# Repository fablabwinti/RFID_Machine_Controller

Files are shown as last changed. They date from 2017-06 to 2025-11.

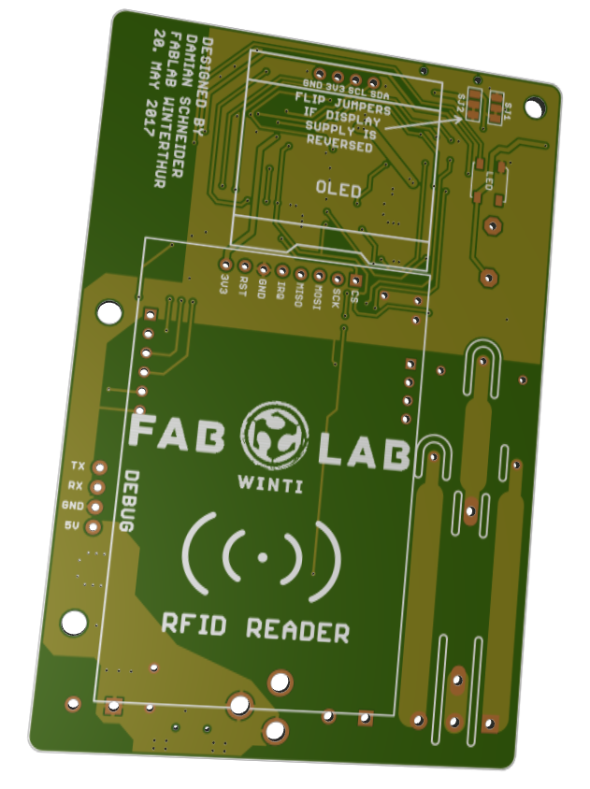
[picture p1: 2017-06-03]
Hardware/PCB_BottomView.PNG

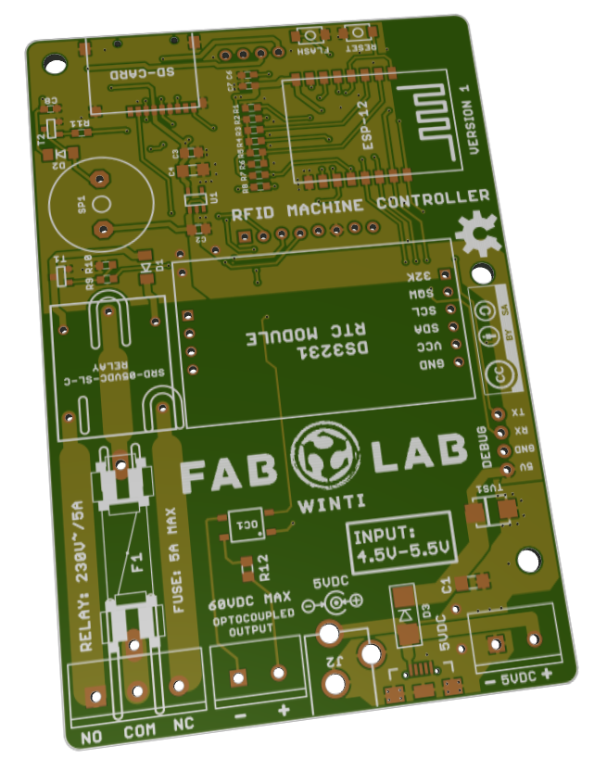
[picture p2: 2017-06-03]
Hardware/PCB_TopView.PNG

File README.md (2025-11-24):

# RFID_Machine_Controller
This repository contains the hardware design files (eagle) and the firmware (Arduino) for the Fablab Winti RFID machine access controller. 
## Hardware features
- Based on ESP8266 so it has direct access to WiFi
- RFID reader 
- OLED display
- Piezo buzzer
- Multi-color LED
- SD card for event logging
- RTC for accurate time keeping without network access
- Isolated output with screw terminal
  - Option 1: Relay output: 250V, 5A, NC or NO with a 5x20mm fuse
  - Option 2: Opto-coupled output (50V, 40mA)
- Input voltage: 5V ±0.5V with input protection (reverse voltage protection, overvoltage protection)
- Three input connecters: 5.5x2.1mm DC jack, Micro USB jack, screw termianl

## Firmware features
- Easy web based configuration
- Time sync through NTP
- Automatic synchronization of local RTC 
- Automatic update of user database from server
- Local storage of access rights: works during network failures
- Local data logging to SD-Card or Flash (TBD)
- Transmit log data to server as soon as it is available

## Arduino IDE
### Add Board to IDE
File -> Preferences -> Settings -> Additional boards manager URLs: http://arduino.esp8266.com/stable/package_esp8266com_index.json  
### Install Board
Tools -> Boards -> Boards Manager
Search for "esp8266" and install it
### Select Board
Tools -> Boards -> esp8622 -> "Generic ESP8622 Module"
### Board Configurations
Select the following settings under "Tools"



### Install Libraries
Unzip "FabLabRFID_Library.zip" in the arduino library folder:

- Windows: `C:\Users\{username}\Documents\Arduino`
- macOS: `/Users/{username}/Documents/Arduino`
- Linux: `/home/{username}/Arduino`

#### Manually

Tools -> Manage Libraries

Install all libraries as described in Fablab_RFID_control.ino, line 52 to 70 (?)

MRFC522: Download from git (https://github.com/miguelbalboa/rfid) and add it to the library (.../Documents/Arduino/Libraries/...)

## Upload Flash Content

The `spiffs_flash.py` script automatically builds the SPIFFS filesystem image from the `data` directory and uploads it to the ESP8266.

### Prerequisites
- Python 3.x installed
- ESP8266 connected via USB
- Arduino15 directory present (auto-detected or manually specified)

### Usage

Basic upload (auto-detects Arduino15 directory):
```bash
python spiffs_flash.py --port COM8
```

With custom options:
```bash
# Specify Arduino15 directory manually
python spiffs_flash.py --port COM8 --arduino-root "C:\Users\YourName\AppData\Local\Arduino15"

# Erase SPIFFS region before writing (if write fails)
python spiffs_flash.py --port COM8 --erase-region

# Keep temporary build files for inspection
python spiffs_flash.py --port COM8 --keep-temp

# Use existing .bin file (skip build)
python spiffs_flash.py --port COM8 --bin path\to\existing.spiffs.bin
```

### Troubleshooting
- If Arduino15 not found, the script will prompt for the path
- Use `--erase-region` if you encounter write errors (preserves main firmware)
- Change COM port number to match your device (check Device Manager on Windows)

# License
-Firmware under GNU LGPL Version 3
-Hardware under Creative Commons 4.0 license: CC-BY-SA

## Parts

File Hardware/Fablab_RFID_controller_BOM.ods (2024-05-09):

Bill of materials for the Fablab RFID machine access conroller / logger
Part | Description | Quantity | Price per piece | Ordering information | Order Quantitiy | Ordering Price
PCB |  | 1 | 2.85 | Seeedstudio, DHL shipping (https://www.seeedstudio.com/fusion_pcb.html) | 10 | 28.5
SUP | 5V 2A Power supply | 1 | 2.84 | Aliexpress (https://www.aliexpress.com/item/1PCS-5V2A-New-AC-100V-240V-Converter-Adapter-DC-5V-2A-2000mA-Power-Supply-EU-Plug/32277477479.html) | 10 | 28.37
TF Card | micro SD card, 2GB | 1 | 2.8 | Aliexpress (https://www.aliexpress.com/item/10pcs-lot-microsd-tf-card-2gb-2gb-micro-tf-card-transflash-2gb-with-free-memory-card/496106309.html) | 10 | 28
C1 | 100uF, 1206, X7R, 16V | 1 | 0.18 | Aliexpress (https://www.aliexpress.com/item/Free-Shipping-50PCS-1206-107M-100UF-20-X7R-16V-chip-SMD-Ceramic-capacitor-3216-1206-SMD/32639706932.html) | 50 | 8.8
C2, C3 | 10uF, 0805, X7R, 25V | 2 | 0.08 | Aliexpress (https://www.aliexpress.com/item/100pcs-lot-10uF-X7R-Error-10-25V-0805-smd-capacitor/32319279591.html) | 100 | 4
C6, C7, C8 | 100nF, 0603, X7R, 50V | 3 | 0.02 | Aliexpress (https://www.aliexpress.com/item/100pcs-lot-100nF-X7R-Error-10-50V-0805-smd-capacitor/32318938808.html) | 500 | 2.7
D1 | 1N4148, Minimelf | 1 | 0 | Aliexpress (https://www.aliexpress.com/item/Free-shipping-100PCS-LL4148-LL-34-1N4148-IN4148-smd-High-speed-switching-diodes/32334460408.html) | 500 | 1.8
D3 | 1A, Schottky, SMA | 1 | 0.01 | Aliexpress (https://www.aliexpress.com/item/Free-shipping-100pcs-sma-1n5819-smd-1A-40V-do-214ac-Schottky-diode-SOt-23-diode-ss14/32337470783.html) | 100 | 1
F1 | Fuse holder | 1 | 0.14 | Aliexpress (https://www.aliexpress.com/item/10PCS-Panel-Mount-PCB-Fuse-Holder-Case-w-Cover-5x20mm-With-Transparent-Cover-5-20-High/32761598754.html) | 10 | 1.4
F1-2 | 5A Fuse, 5x20mm | 1 | 0.15 | Aliexpress (https://www.aliexpress.com/item/50pcs-Ceramic-tube-6-30mm-20A-250V-6X30-Quick-break-F20A/32523716039.html) | 30 | 4.5
B1, B2 | Tactaile button | 2 | 0.15 | Aliexpress (https://www.aliexpress.com/item/20pcs-smd-3-4-2MM-Micro-button-3X4X2-tact-switch-2-pin-little-turtle-single-shrapnel/32530022647.html) | 20 | 1.45
SD | SD-Card Slot | 1 | 0.27 | Aliexpress (https://www.aliexpress.com/item/10pcs-lot-Trans-Flash-TF-Micro-SD-Card-Socket-Adapter-pop-up-micro-TF-memory-card/32297753919.html) | 10 | 2.7
J1 | 5.5x2.1 DC Jack | 1 | 0.06 | Aliexpress (https://www.aliexpress.com/item/20PCS-LOT-DC-005-Black-and-White-DC-Power-Jack-Socket-Connector-DC005-5-5-2/32730260523.html) | 20 | 1.15
JP6 | Screw Terminal 3P | 1 | 0.15 | Aliexpress (https://www.aliexpress.com/item/10Pcs-Lot-KF301-3P-KF301-5-0MM-3P-Blue-KF301-Screw-3Pin-5-0mm-Straight/32732383478.html) | 20 | 3
JP8, JP9 | Screw Terminal 2P | 2 | 0.3 | Aliexpress (https://www.aliexpress.com/item/10Pcs-5mm-5-08mm-2Pins-2P-2-PINS-PCB-Screw-Terminal-Block-Connectors-300V-10A-DG128/32691479684.html) | 10 | 1.5
LED | WS2812B | 1 | 0.25 | Aliexpress (https://www.aliexpress.com/item/10-1000pcs-WS2812B-4pins-5050-SMD-Black-White-version-WS2812-Individually-Addressable-Digital-RGB-LED-Chip/32453497583.html) | 10 | 2.5
OC1 | EL357 optocoupler | 1 | 0.07 | Aliexpress (https://www.aliexpress.com/item/Free-shipping-20pcs-EL357NC-SMD-Optocoupler-EL357-EL357N/32341947060.html) | 20 | 1.3
R1, R2, R3, T4, R5, R7, R10, R13 | 10k, 0603 | 8 | 0.08 | Aliexpress 0603 Resistor Kit (https://www.aliexpress.com/item/Free-shipping-Hot-sale-0603-SMD-Resistor-Kit-Assorted-Kit-1ohm-10M-ohm-1-36valuesX20pcs-720pcs/32359683117.html) | 20 | 1.85
R6, R9, R11, R12 | 1k, 0603 | 4 | 0.04
R8 | 510R, 0603 | 1 | 0.01
SP1 | Piezo Speaker | 1 | 0.29 | Aliexpress (https://www.aliexpress.com/item/10pcs-Piezoelectric-Piezo-Passive-Electronic-Buzzer-Speaker-14-7-Loudspeaker-1407-5V-14x7mm-4KHz-2mA-Black/32802296078.html) | 10 | 2.85
T1, T2 | NPN 40V, 0.6A SOT23 | 2 | 0.03 | Aliexpress (https://www.aliexpress.com/item/MMBT2222A-SOT-23-500pcs-lot-Triode-Transistor/32311239794.html) | 100 | 1.4
TVS1 | SMBJ5.0CA | 1 | 0.06 | Aliexpress (https://www.aliexpress.com/item/Free-shipping-20pcs-600W-SMB-DO-214AA-smd-tvs-diode-SMBJ5-0CA/32338238265.html) | 20 | 1.2
OLED | 0.96" OLED Display | 1 | 2.56 | Aliexpress (https://www.aliexpress.com/item/10pcs-0-96-white-0-96-inch-OLED-module-New-128X64-OLED-LCD-LED-Display-Module/32643753358.html) | 10 | 25.6
USB | Micro USB Jack | 1 | 0.03 | Aliexpress (https://www.aliexpress.com/item/10PCS-RT9013-33PB-RT9013-SOT23-5-RT9013-33/32699079131.html) | 100 | 3.3
REL1 | SRD-05VDC-SL-C Relay | 1 | 0.56 | Aliexpress (https://www.aliexpress.com/item/T73-5VDC-SONGLE-Power-Relay-SRD-05VDC-SL-C-PCB-Type-20pcs-Free-Shipping/32520810798.html) | 20 | 11.2
ESP | ESP-12F Module | 1 | 2.13 | Aliexpress (https://www.aliexpress.com/item/10pcs-2015-New-version-1PCS-ESP-12F-ESP-12E-upgrade-ESP8266-remote-serial-Port-WIFI-wireless/32589865366.html) | 10 | 21.3
RFID | MFRC-522 Module | 1 | 1.69 | Aliexpress (https://www.aliexpress.com/item/MFRC-522-RC522-RFID-RF-IC-card-sensor-module-to-send-S50-Fudan-card-keychain-for/1654370096.html) | 10 | 16.9
RTC | DS3231 RTC Module | 1 | 1.36 | Aliexpress (https://www.aliexpress.com/item/MFRC-522-RC522-RFID-RF-IC-card-sensor-module-to-send-S50-Fudan-card-keychain-for/1654370096.html) | 10 | 13.6
IC1 | RT9013-33PB SOT23-5 | 1 | 0.2 | Aliexpress (https://www.aliexpress.com/item/10PCS-RT9013-33PB-RT9013-SOT23-5-RT9013-33/32699079131.html) | 20 | 3.98
 | Price per Unit* |  | 19.34 |  | Total Order Price | 225.85
*if ordering of exactly 10 parts

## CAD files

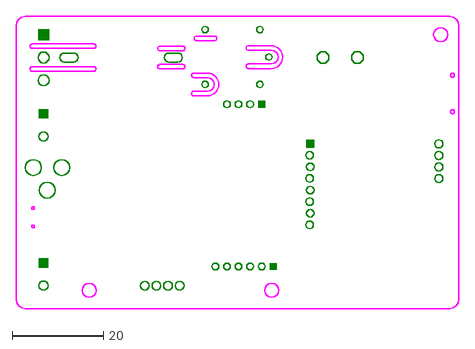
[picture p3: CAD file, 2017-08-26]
Hardware/Fablab_RFID_conroller_V1.dxf
97.0 x 64.0

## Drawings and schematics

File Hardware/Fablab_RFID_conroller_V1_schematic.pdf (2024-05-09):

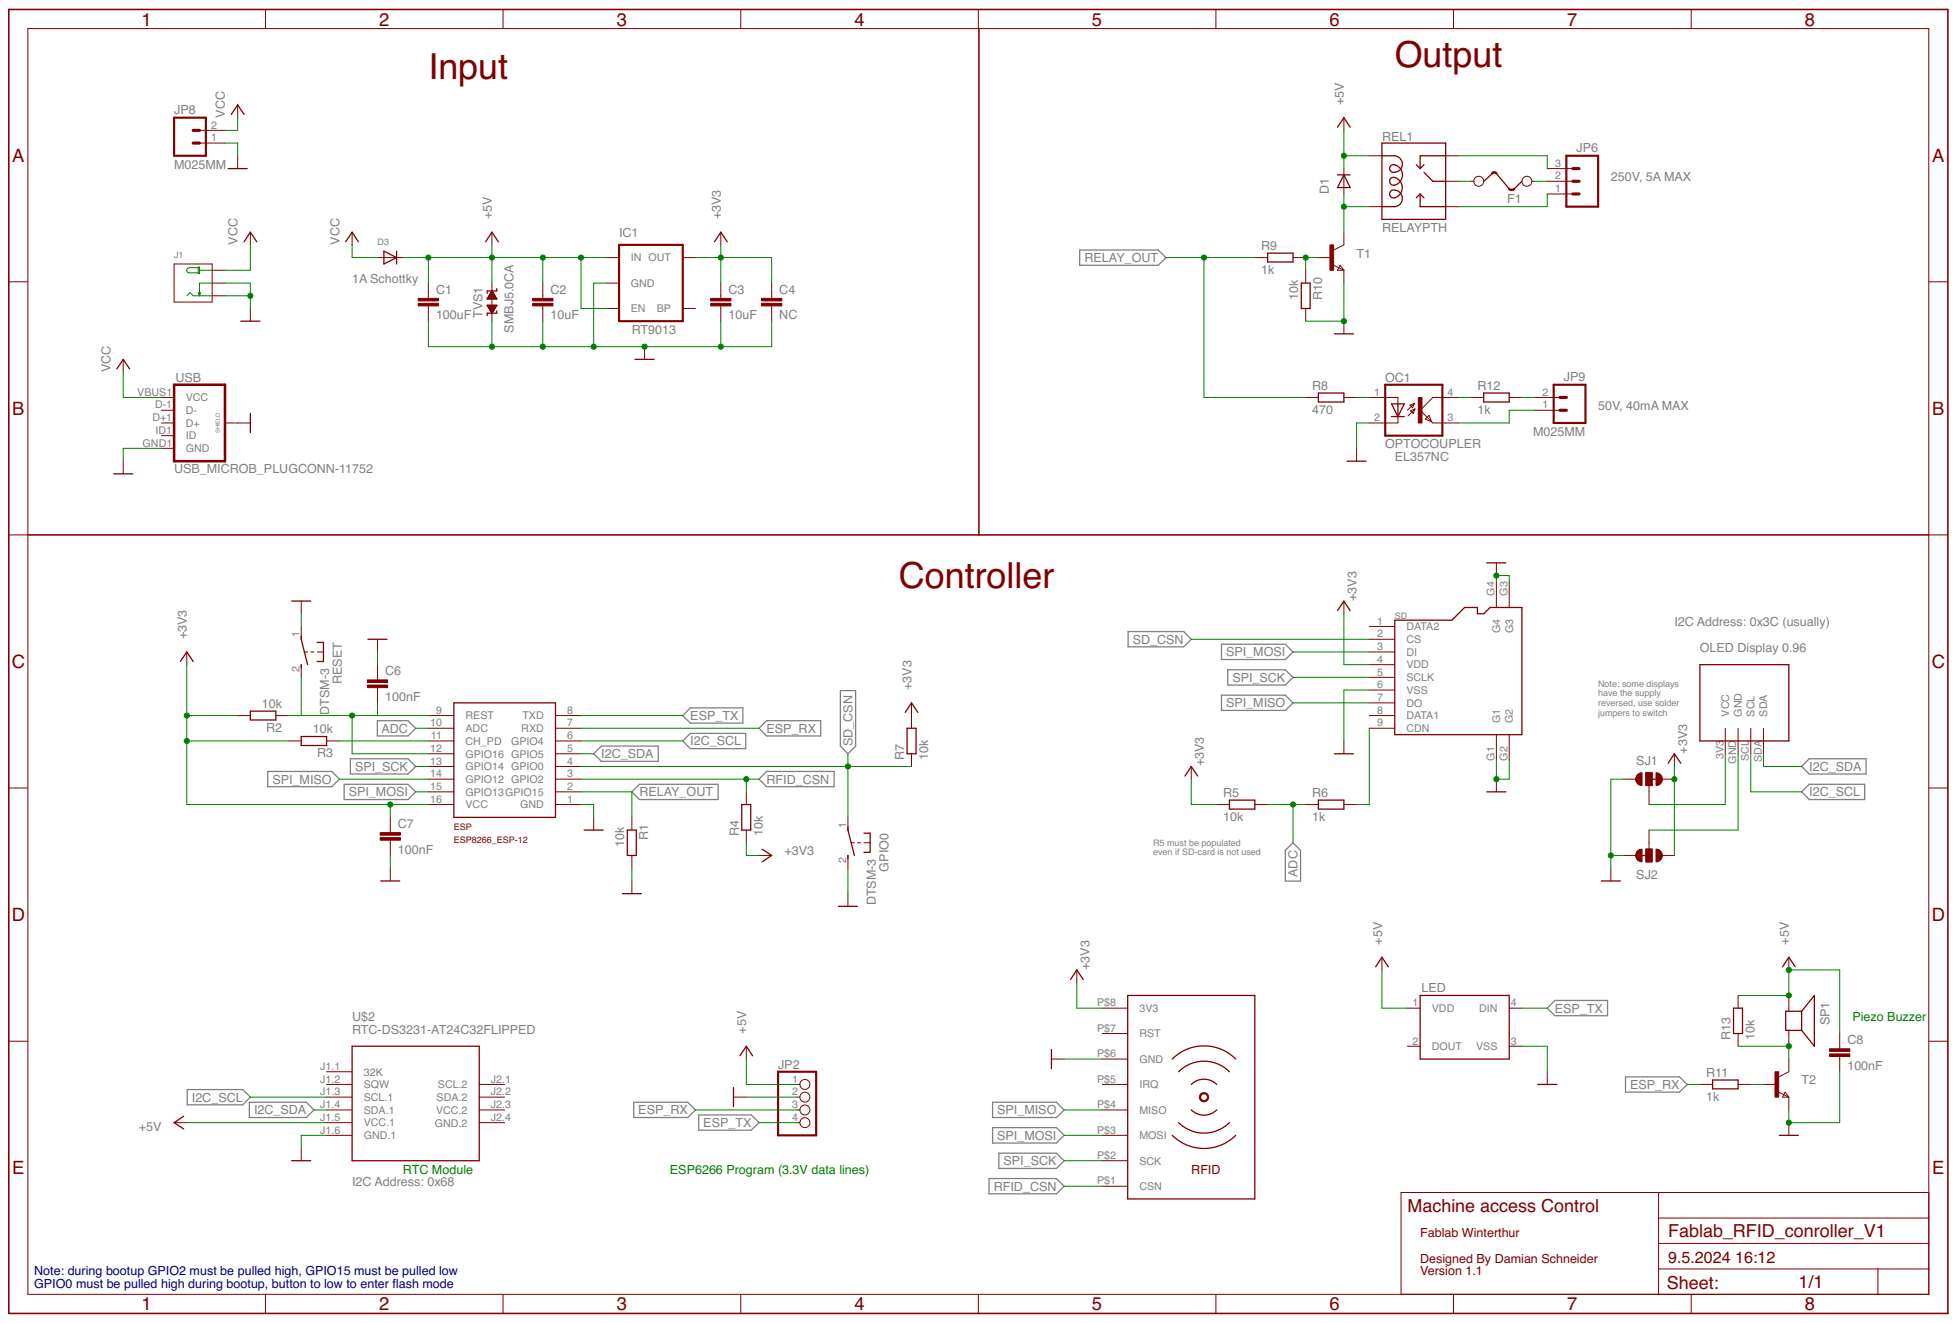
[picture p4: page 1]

Input | Output

Note: some displays have the supply

3 GPIO0 2 GPIO2

R5 must be populated
even if SD-card is not used

Machine access Control Fablab Winterthur Designed By Damian Schneider Version 1.1

Note: during bootup GPIO2 must be pulled high, GPIO15 must be pulled low GPIO0 must be pulled high during bootup, button to low to enter flash mode

Sheet: 1/1

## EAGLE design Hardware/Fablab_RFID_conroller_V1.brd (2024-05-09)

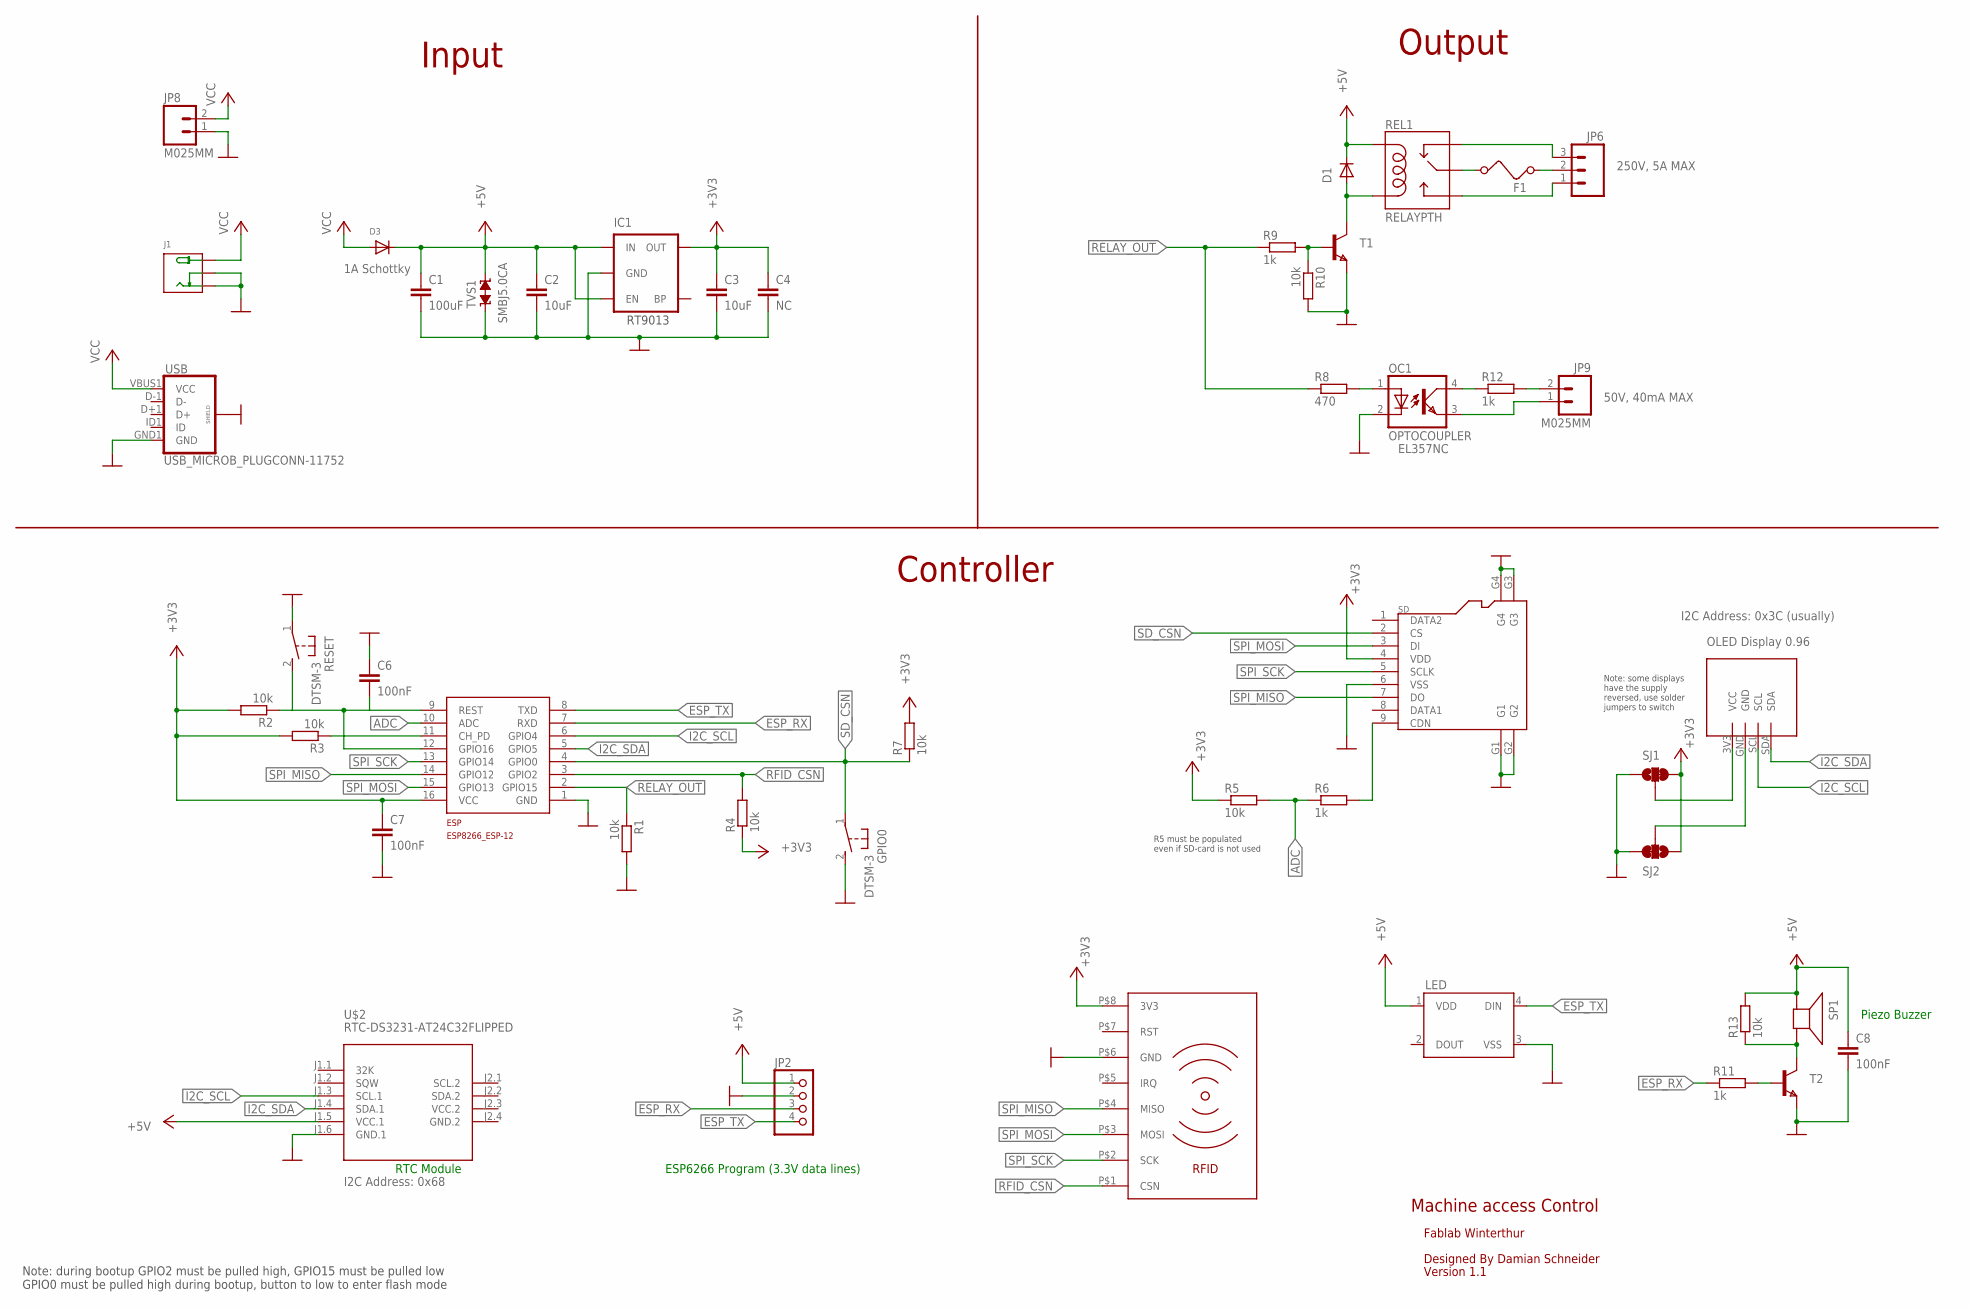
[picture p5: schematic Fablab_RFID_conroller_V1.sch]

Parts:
C1: 100uF; C1206
C2, C3: 10uF; C0805
C4: NC; C1206
C6, C7, C8: 100nF; C0603
D1: DIODE-MINIMELF; MINIMELF
D3: DIODESMA; SMADIODE
ESP: ESP8266_ESP-12; ESP8266-ESP12
F1: FUSE
GPIO0: DTSM-3
IC1: V_REG_LDOSMD; SOT23-5
J1: JACK-DC-3P-3410020P1; PW-3P-2.1
JP2: HEADER-1X476MIL; 1X04_ROUND_76
JP6: M03-SCREW-5MM; SCREWTERMINAL-5MM-3
JP8, JP9: M025MM; SCREWTERMINAL-5MM-2
LED: WS2812B
OC1: OPTOCOUPLER; SOP04
OLED: OLED_0.96_I2CNOHOLES; OLED_0.96_I2C_NOHOLES
R1, R2, R3, R4, R5, R7, R10, R13: 10k; R0603
R6, R9, R11: 1k; R0603
R8: 470; R0603
R12: 1k; R0805
REL1: RELAYPTH; SRD-05VDC-SL-C
RESET: DTSM-3
RFID: RFID_MODULE_RC522; RFID-RC522-MODULE
SD: MICRO-SDCARD-CONNECTOR-3300060P1; 9P-SMD-W-RING
SJ1, SJ2: JUMPER-PAD-3-2OF3_NC_BY_TRACE_LARGE; PAD-JUMPER-3-2OF3_NC_BY_TRACE_YES_SILK_LARGE
SP1: SPEAKER/AL60P; AL60P
T1, T2: NPNSOT23; SOT-23
TVS1: TVS-SMBJ; SMBJ
U$2: RTC-DS3231-AT24C32FLIPPED; RTC-DS3231_FLIPPED
USB: USB_MICROB_PLUGCONN-11752; USB-B-MICRO-SMD_V03

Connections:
!SDCARD_DETECT: R6.2, SD.9 (CDN)
+3V3: C3.1, C4.1, C7.1, ESP.16 (VCC), IC1.5 (OUT), R2.2, R3.2, R4.1, R5.1, R7.2, RFID.P$8 (3V3), SD.4 (VDD), SJ1.3, SJ2.1
+5V: C1.1, C2.1, C8.1, D1.C, D3.C, IC1.1 (IN), IC1.3 (EN), JP2.1, LED.1 (VDD), R13.2, REL1.COIL1, SP1.1 (+), TVS1.C (2), U$2.J1.5 (VCC.1)
ADC: ESP.10 (ADC), R5.2, R6.1
CHPD: ESP.11 (CH_PD), R3.1
ESP_RX: ESP.7 (RXD), JP2.3, R11.1
ESP_TX: ESP.8 (TXD), JP2.4, LED.4 (DIN)
GND: C1.2, C2.2, C3.2, C4.2, C6.1, C7.2, C8.2, ESP.1 (GND), GPIO0.2, IC1.2 (GND), J1.-1 (-), J1.-2 (CDN), JP2.2, JP8.1, LED.3 (VSS), OC1.2 (C), R1.2, R10.2, RESET.1, RFID.P$6 (GND), SD.6 (VSS), SD.G1, SD.G2, SD.G3, SD.G4, SJ1.1, SJ2.3, T1.2 (E), T2.2 (E), TVS1.A (1), U$2.J1.6 (GND.1), USB.GND1 (GND), USB.SHIELD1 (SHIELD), USB.SHIELD2 (SHIELD), USB.SHIELD3 (SHIELD)
GND.2: U$2.J2.4 (GND.2)
I2C_SCL: ESP.6 (GPIO4), OLED.SCL, U$2.J1.3 (SCL.1)
I2C_SDA: ESP.5 (GPIO5), OLED.SDA, U$2.J1.4 (SDA.1)
unnamed: JP9.2, R12.2
unnamed: OLED.3V3 (VCC), SJ1.2
unnamed: OLED.GND, SJ2.2
unnamed: R9.2, R10.1, T1.3 (B)
unnamed: D1.A, REL1.COIL0, T1.1 (C)
unnamed: R13.1, SP1.2 (-), T2.1 (C)
unnamed: R11.2, T2.3 (B)
unnamed: F1.1, JP6.2
unnamed: JP6.1, REL1.SW_NO (SWOPEN)
unnamed: F1.2, REL1.SWCOMMON
unnamed: JP6.3, REL1.SW_NC (SWCLOSE)
unnamed: OC1.1 (A), R8.2
unnamed: OC1.4 (COL), R12.1
unnamed: JP9.1, OC1.3 (EMIT)
RELAY_OUT: ESP.2 (GPIO15), R1.1, R8.1, R9.1
RESET: C6.2, ESP.9 (REST), ESP.12 (GPIO16), R2.1, RESET.2
RFID_CSN: ESP.3 (GPIO2), R4.2, RFID.P$1 (CSN)
SD_CSN: ESP.4 (GPIO0), GPIO0.1, R7.1, SD.2 (CS)
SPI_MISO: ESP.14 (GPIO12), RFID.P$4 (MISO), SD.7 (DO)
SPI_MOSI: ESP.15 (GPIO13), RFID.P$3 (MOSI), SD.3 (DI)
SPI_SCK: ESP.13 (GPIO14), RFID.P$2 (SCK), SD.5 (SCLK)
VCC: D3.A, J1.+, JP8.2, USB.VBUS1 (VCC)
VCC.2: U$2.J2.3 (VCC.2)

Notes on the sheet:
ESP6266 Program (3.3V data lines)
Note: during bootup GPIO2 must be pulled high, GPIO15 must be pulled low GPIO0 must be pulled high during bootup, button to low to enter flash mode
Piezo Buzzer
OLED Display 0.96
R5 must be populated even if SD-card is not used
RTC Module
RT9013
Machine access Control
Fablab Winterthur
Designed By Damian Schneider
EL357NC
50V, 40mA MAX
250V, 5A MAX
I2C Address: 0x68
I2C Address: 0x3C (usually)
1A Schottky
SMBJ5.0CA
Input
Output
Controller
Note: some displays have the supply reversed, use solder jumpers to switch
Version 1.1

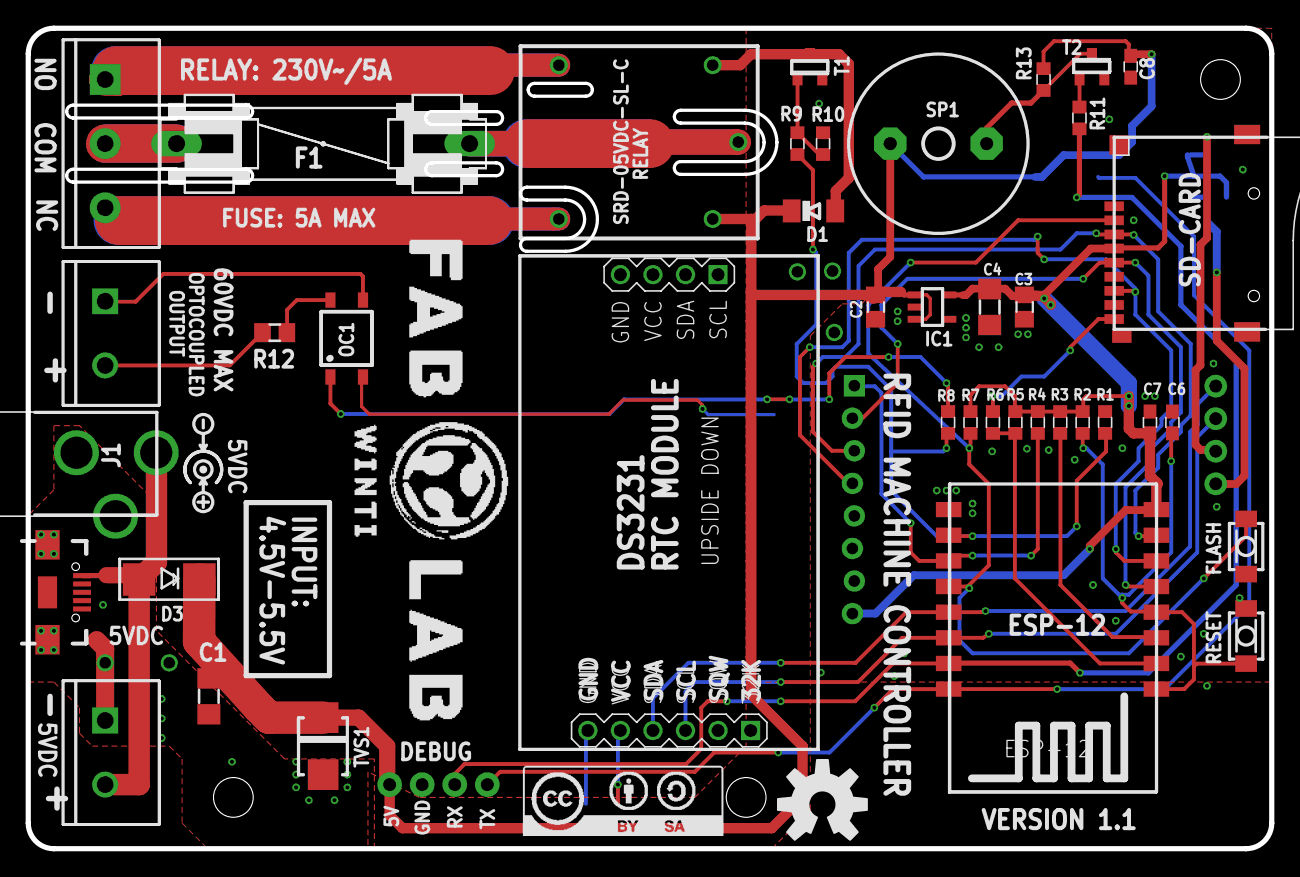
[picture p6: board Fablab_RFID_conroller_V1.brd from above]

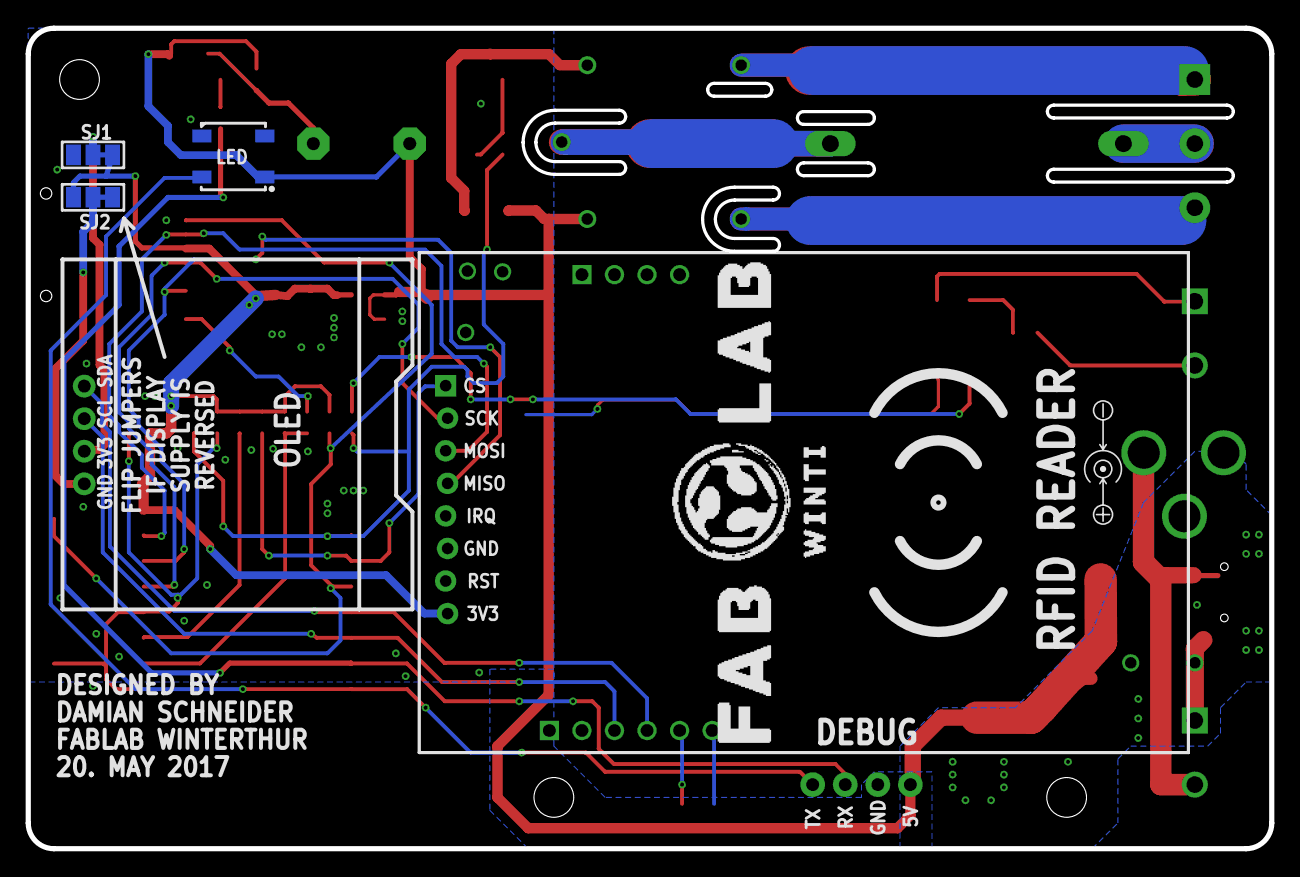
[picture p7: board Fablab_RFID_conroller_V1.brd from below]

Board: 2 copper layers, 97.0 x 64.0 mm, 47 parts (5 on the bottom side), 32 nets.

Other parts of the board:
U$6: OSHW-LOGO-L

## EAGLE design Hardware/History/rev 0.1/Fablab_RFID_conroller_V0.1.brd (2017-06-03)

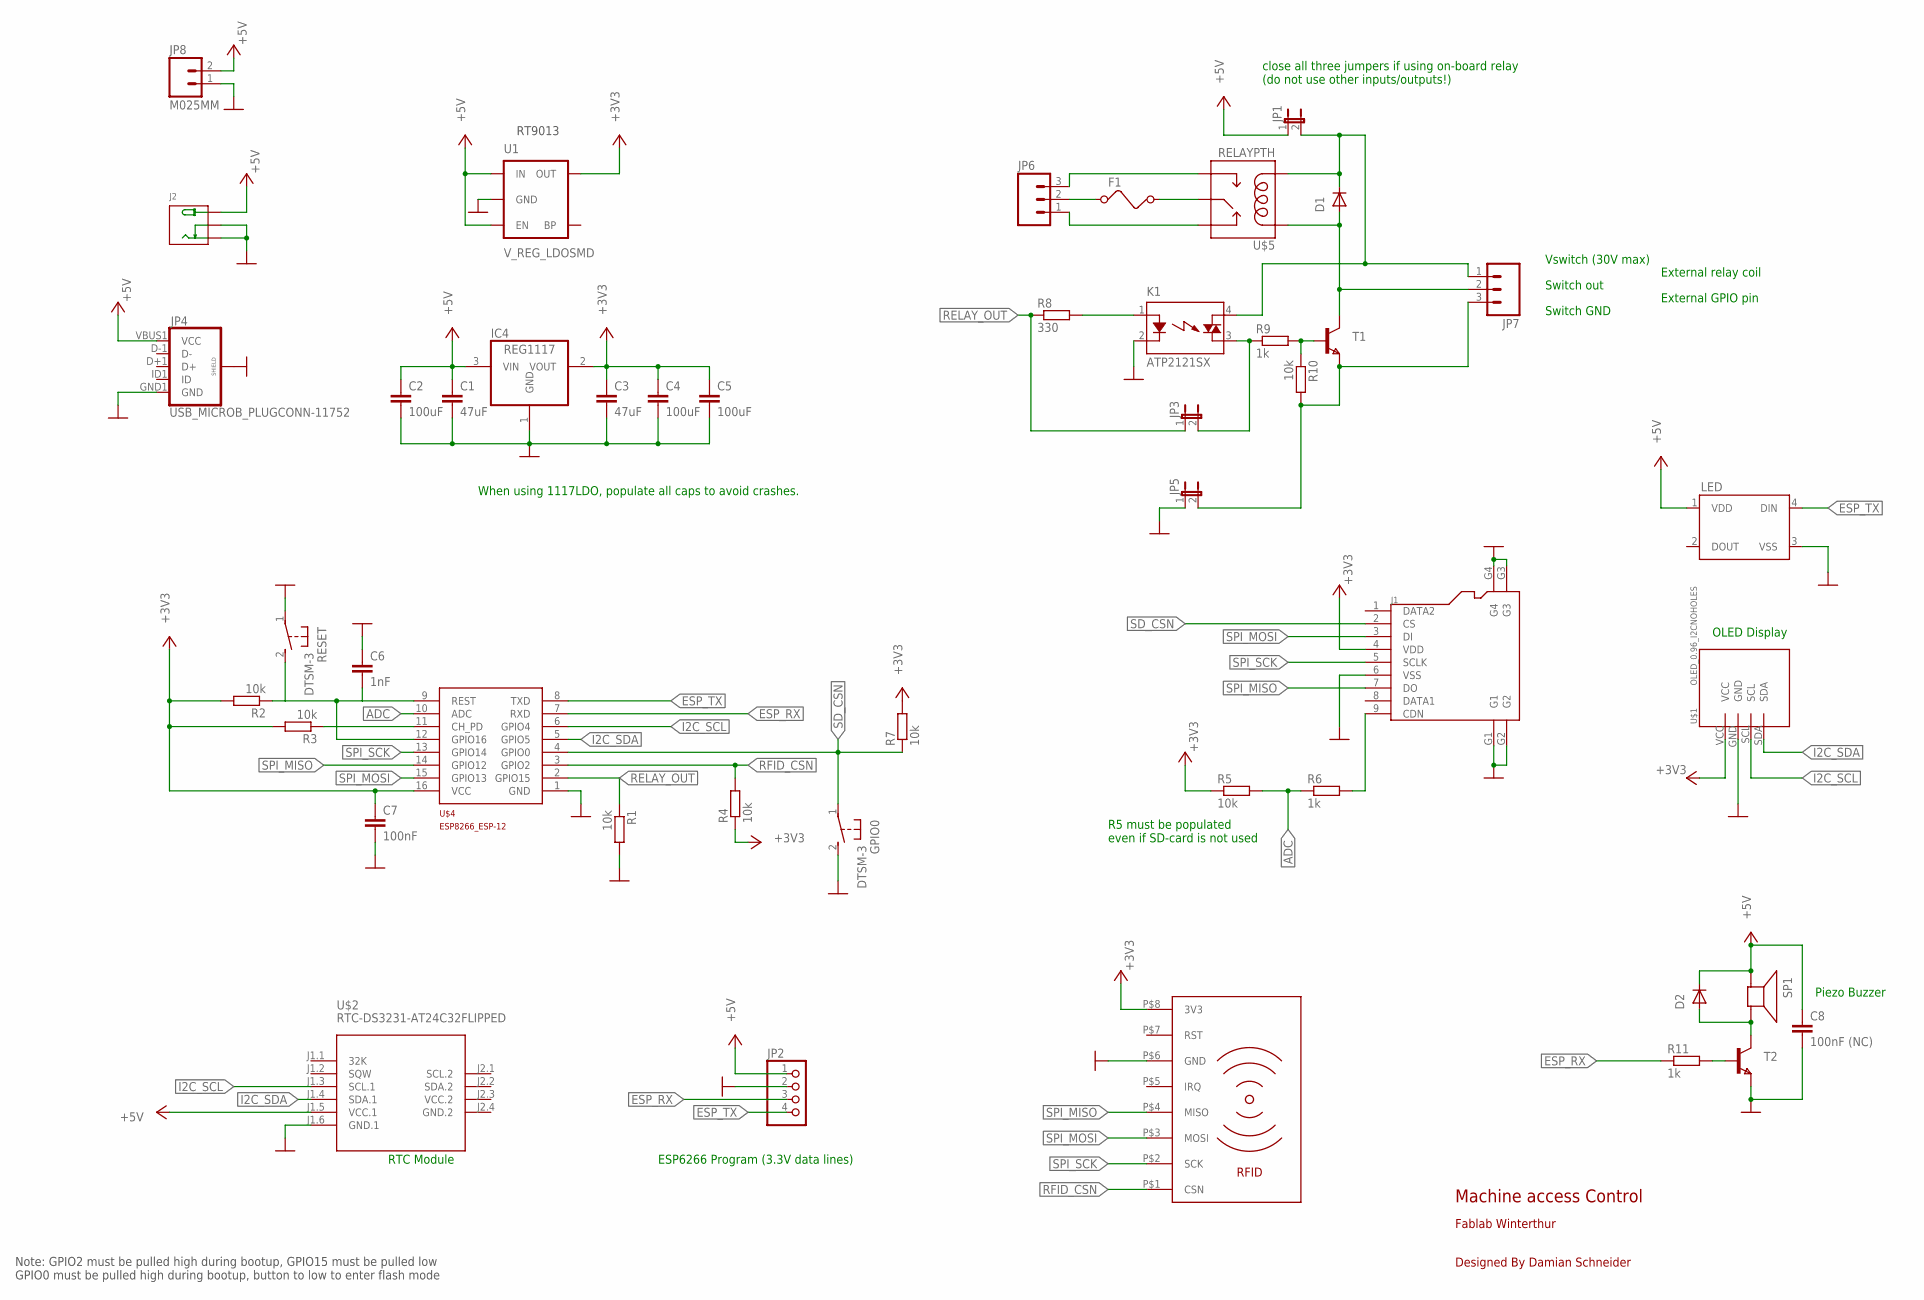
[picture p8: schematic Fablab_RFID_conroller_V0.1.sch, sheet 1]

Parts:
C1, C3: 47uF; C0805
C2, C4, C5: 100uF; C1206
C6: 1nF; C0603
C7: 100nF; C0603
C8: 100nF (NC); C0603
D1, D2: DIODE-MINIMELF; MINIMELF
F1: FUSE
GPIO0: DTSM-3
IC4: REG1117; SOT223
J1: MICRO-SDCARD-CONNECTOR-3300060P1; 9P-SMD-W-RING
J2: JACK-DC-3P-3410020P1; PW-3P-2.1
JP1, JP3, JP5: JP1E; JP1
JP2: HEADER-1X476MIL; 1X04_ROUND_76
JP4: USB_MICROB_PLUGCONN-11752; USB-B-MICRO-SMD_V03
JP6, JP7: M03-SCREW-5MM; SCREWTERMINAL-5MM-3
JP8: M025MM; SCREWTERMINAL-5MM-2
K1: ATP2121SX; SOP04
LED: WS2812B
R1, R2, R3, R4, R5, R7, R10: 10k; R0603
R6, R9, R11: 1k; R0603
R8: 330; R0603
RESET: DTSM-3
SP1: SPEAKER/AL60P; AL60P
T1, T2: NPNSOT23; SOT-23
U1: V_REG_LDOSMD; SOT23-5
U$1: OLED_0.96_I2CNOHOLES; OLED_0.96_I2C_NOHOLES
U$2: RTC-DS3231-AT24C32FLIPPED; RTC-DS3231_FLIPPED
U$3: RFID_MODULE_RC522; RFID-RC522-MODULE
U$4: ESP8266_ESP-12; ESP8266-ESP12
U$5: RELAYPTH; SRD-05VDC-SL-C

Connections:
!SDCARD_DETECT: J1.9 (CDN), R6.2
+3V3: C3.1, C4.1, C5.1, C7.1, IC4.2 (VOUT), J1.4 (VDD), R2.2, R3.2, R4.1, R5.1, R7.2, U1.5 (OUT), U$1.VCC, U$3.P$8 (3V3), U$4.16 (VCC)
+5V: C1.1, C2.1, C8.1, D2.C, IC4.3 (VIN), J2.+, JP1.1, JP2.1, JP4.VBUS1 (VCC), JP8.2, LED.1 (VDD), SP1.1 (+), U1.1 (IN), U1.3 (EN), U$2.J1.5 (VCC.1)
ADC: R5.2, R6.1, U$4.10 (ADC)
CHPD: R3.1, U$4.11 (CH_PD)
ESP_RX: JP2.3, R11.1, U$4.7 (RXD)
ESP_TX: JP2.4, LED.4 (DIN), U$4.8 (TXD)
GND: C1.2, C2.2, C3.2, C4.2, C5.2, C6.1, C7.2, C8.2, GPIO0.2, IC4.1 (GND), J1.6 (VSS), J1.G1, J1.G2, J1.G3, J1.G4, J2.-1 (-), J2.-2 (CDN), JP2.2, JP4.GND1 (GND), JP4.SHIELD1 (SHIELD), JP4.SHIELD2 (SHIELD), JP4.SHIELD3 (SHIELD), JP5.1, JP8.1, LED.3 (VSS), R1.2, RESET.1, T2.2 (E), U1.2 (GND), U$1.GND, U$2.J1.6 (GND.1), U$3.P$6 (GND), U$4.1 (GND)
GND.2: U$2.J2.4 (GND.2)
I2C_SCL: U$1.SCL, U$2.J1.3 (SCL.1), U$4.6 (GPIO4)
I2C_SDA: U$1.SDA, U$2.J1.4 (SDA.1), U$4.5 (GPIO5)
unnamed: K1.1 (A), R8.2
unnamed: JP3.2, K1.3 (DS2), R9.1
unnamed: R9.2, R10.1, T1.3 (B)
unnamed: D1.A, JP7.2, T1.1 (C), U$5.COIL1
unnamed: JP5.2, JP7.3, R10.2, T1.2 (E)
unnamed: D2.A, SP1.2 (-), T2.1 (C)
unnamed: JP1.2, JP7.1, K1.4 (DS1)
unnamed: D1.C, U$5.COIL0
unnamed: R11.2, T2.3 (B)
unnamed: F1.1, JP6.2
unnamed: JP6.3, U$5.SW_NO (SWOPEN)
unnamed: F1.2, U$5.SWCOMMON
unnamed: JP6.1, U$5.SW_NC (SWCLOSE)
RELAY_OUT: JP3.1, R1.1, R8.1, U$4.2 (GPIO15)
RESET: C6.2, R2.1, RESET.2, U$4.9 (REST), U$4.12 (GPIO16)
RFID_CSN: R4.2, U$3.P$1 (CSN), U$4.3 (GPIO2)
SD_CSN: GPIO0.1, J1.2 (CS), R7.1, U$4.4 (GPIO0)
SPI_MISO: J1.7 (DO), U$3.P$4 (MISO), U$4.14 (GPIO12)
SPI_MOSI: J1.3 (DI), U$3.P$3 (MOSI), U$4.15 (GPIO13)
SPI_SCK: J1.5 (SCLK), U$3.P$2 (SCK), U$4.13 (GPIO14)
VCC.2: U$2.J2.3 (VCC.2)

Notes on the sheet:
ESP6266 Program (3.3V data lines)
Note: GPIO2 must be pulled high during bootup, GPIO15 must be pulled low GPIO0 must be pulled high during bootup, button to low to enter flash mode
Piezo Buzzer
OLED Display
R5 must be populated even if SD-card is not used
RTC Module
Vswitch (30V max)
Switch GND
Switch out
External relay coil
External GPIO pin
close all three jumpers if using on-board relay (do not use other inputs/outputs!)
RT9013
When using 1117LDO, populate all caps to avoid crashes.
Machine access Control
Fablab Winterthur
Designed By Damian Schneider

Board: 2 copper layers, 46 parts (3 on the bottom side), 30 nets, no tracks yet.

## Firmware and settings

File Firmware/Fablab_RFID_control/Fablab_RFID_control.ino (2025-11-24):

/*
  Hardare: Use only ESP8266 with 4M of flash, then select 4M (with 2M SPIFFS) (need extras sketch space to enable update throug webpage and future increases, 2M SPIFFS is plenty)

  TODO: add license here ( GNU LGPL Version 3 ), also add license to GIT repo

  FabLab RFID controller, by Damian Schneider, www.fablabwinti.ch
  GIT: https://github.com/fablabwinti/RFID_Machine_Controller



  Tested on Arduino 1.8.5 using ESP8266 Arduino V2.4.0  (https://github.com/esp8266/Arduino/releases)
  For tested library versions, see next to their includes.



  Note on data structure

  -the configuration of the node resides in "eeprom" (flash actually). this includes:
    -wifi configuration
    -machine ID, machine name, machine pricing
    -admin tags & access codes

  -the SPIFF file system contains
    -the config web page
    -user IDs and access control stuff (in a database file)
  -logging is done on the SD card:
    -system event log files:
      -booting/rebooting/crash
      -server communication log
      -web page access
  -user login/logout is saved to a separate event database, it is either in SPIFFS or on SD
      -uid, username, transferred to server flag

  Other notes:
    -the display must show: current user name, log time, running price
    -when not logging: current time&date, machine name, machine pricing
    -at bootup: show logo or something
    -maximum number of users: 2000 (limited by database size, can probably be increased but is untested)

    -while a user is logged in, any network activity (RTC sync, sendout events, webpage etc.) are disabled to ensure best stability while the machine is running

  Admin interface stuff:
    -administration is done through the web page
    -the webpage can be activeted only by pressing the function button on the hardware (after bootup)
    -

    Tested on Arduino 1.8.9 and 1.8.12
    ESP version 2.5.2 (Not working with 2.6.x !!! something changed in the wifisecure library)

    Libraries used:
  Using library EDB at version 1.0.4   https://github.com/jwhiddon/EDB
  Using library SPI at version 1.0
  Using library MRFC522 at version 1.4.10
  Using library FastLED at version 3.2.1
  Using library Time at version 1.5   https://github.com/PaulStoffregen/Time
  Using library Rtc_by_Makuna at version 2.0.2   https://github.com/Makuna/Rtc
  Using library Adafruit_SSD1306 at version 1.1.2
  Using library Adafruit_GFX at version 1.2.3
  Using library ESP8266WiFi at version 1.0
  Using library ESP8266WebServer at version 1.0
  Using library ESP8266HTTPClient at version 1.2
  Using library ESP8266httpUpdate at version 1.3
  Using library EEPROM at version 1.0
  Using library Wire at version 1.0
  Using library ESP8266SdFat at version 1.0.16
  Using library ESP8266mDNS at version 1.2
  Using library WebSockets at version 2.0.9
  Using library ArduinoJson at version 6.12.0   https://bblanchon.github.io/ArduinoJson/

 * */

//set these compile time parameters to fit your needs
//#define SERIALDEBUG //define this to get serial console output, LED is disabled if serial output is used

#define TIMEZONE 1 //GMT +1  adjust to your timezone if needed, can be negative
#define SERVERMININTERVAL 1000  // minimum interval (in ms) between server sendouts (where a pending event is sent) default: 1000
#define MULTIWIFIS 2 //number of wifi credentials to store for wifi multi (uses lots of ram in the config!) default: 2
#define SAVE_LOG_TO_SD 1 //if defined, strings sent to the server are also written to the SD (if sendout is successful making it a copy of what should be in the server database)
//#define EVENT_DB_TO_SD 1 //if defined, the event database is saved to the SD-card instead of SPIFFS (useful if writing events every few seconds, usage of spiffs is fine when writing like once per minute or less, spiffs will last 100 million entries or more)

//extern "C" {
//#include "user_interface.h" //for light sleep stuff
//}
#define FS_NO_GLOBALS //allow spiffs to coexist with SD card
#define FASTLED_ESP8266_RAW_PIN_ORDER

#include <FS.h> //spiff file system
#include <EDB.h>
#include <SPI.h>
#include <MFRC522.h> //RFID library
#include <FastLED.h> // (need to comment line 15 in led_sysdefs_esp8266.h on lates esp version, boolean error)
#include <TimeLib.h>  //Time library
#include "RtcDS3231.h" //RTC library by makuna
#include <Adafruit_SSD1306.h> //oled display library
#include <Adafruit_GFX.h>
#include <ESP8266WiFi.h>
#include <ESP8266WiFiMulti.h>
//#include <WiFiClient.h>
#include <WiFiClientSecure.h>
#include <ESP8266WebServer.h>
#include <ESP8266HTTPClient.h>
#include <ESP8266httpUpdate.h>
#include <EEPROM.h>
#include <WiFiUdp.h>
#include <IPAddress.h>
#include <Wire.h>
//#include <SD.h> //SD library has bugs, can often lead to crashes (not even the readwrite example works....)
#include "SdFat.h" //
using namespace sdfat;
#include <ESP8266mDNS.h>  //works on mac out of the box, need to install apple's 'Bonjour' service to work on other systems
#include <WebSocketsServer.h>
#include <ArduinoJson.h>
#include "helpers.h"
#include "sound.h"
#include "LED.h"
#include "global.h"
#include "database.h"
#include "display.h"
#include "RTC.h" //real time clock and other time management
#include "NTP.h" //network time protocol management
#include "SDcard.h"
#include "WiFi.h"
#include "ServerRequests.h"
#include "output.h"
#include "webpage.h"
#include "RFID.h"




// SPI pin configuration figured out from here:
// http://d.av.id.au/blog/esp8266-hardware-spi-hspi-general-info-and-pinout/

/*  TODO
 * *******
  -add global flags for: SD state, WIFI state, Server connection state, database state
  -if saving to SD card fails or if connection to server fails multiple times, increase the time between server connect attempts to not slow down normal operation too frequently
  -create a config section for all compile time config stuff (started putting it on beginning of this file, complete?)
  -create log file structure
  -add SSL to all server traffic
  -add SD card viewer to webpage
  --
  -IMPORTANT BUGFIX: in case RTC fails, the controller has to display a huge warning! also, update has to be forced more frequently!
  -optimize ram usage of local config (currently it is fully copied to ram and always kept there using over 512bytes of ram)
  -switch to async web server (more stable) -> not for now
  -refactor everything, use a better edito!
  -make sure there are no infinite loops in the code (cannot guarantee that in any library)
  -what happens if the database on the SD card is full?

  IN PROGRESS:



  DONE:
   -add admin key (UID) that can be updated on webpage and is not deleted on a factory reset -> admin key always works no matter what. (done)
     -> also need to add possibility to do factory reset if program is stuck in an infinite reboot loop -> show boot screen longer while flash key is pressed during bootup, allowing the mode to change (done)
   -add more debug outputs to websocket print (see example in verifyRFIDdata() )
   -add time control for access
   -program a cache function that writes log entries to the SD card. one log file per month or something and one file for 'unsent messages' or better: create a database on the sd card for entries, add a flag and clear it if the entry was sent out succesfully. -> DONE
  -need a solid way to handle the admin key, independant of timer (in case no time is available from RTC or NTP to unlock the machine) -> DONE
   -add a config variable for the key stored in the first sector (same key for all cards), adds security to make cards impossible to be copied (easily) as access to this sector is restricted -> DONE
   -add a config key for password to access the RFID cards first sector ->DONE
   -add possibility to update spiffs through webpage -> DONE
   -add buzzer support -> DONE
   -clean out unused stuff -> DONE
   -add user database -> DONE
   -maybe: add sleep functions to save power -> still need to check the RFID module like every 100ms -> DONE
   -parse incoming json string
   -json input and output functions for database
   -make web-page access restricted by password
   -add firmware update password to eeprom -> NO, it can only be changed in the code
   -read log files on bootup, transfer flagged events to server and unflag them -> DONE
   -add RTC support -> DONE
   -add OLED support -> basic functionality: DONE
   -add RFID support -> basic functionality: DONE
   -use fastled instead of neopixel
   -add timezone and automatic daylightsaving adjustment (for europe, us has different DST rules) -> DONE
   -add timezone to EEPROM and make selectable on webconfig -> NO, must be set in code before compiling
   -put server address into eeprom, make it configurable on webpage
   -fix webpage bug: when sending DHCP settings the page does reload -> done
   -make all webpage traffic websocket based (is currently partially HTTP based which is less secure as passwords and stuff get sent through the URL and will be stored in browser history)
   -add more websocket messages throughout the code, especially in the webpage & config section
   -make the access to webpage and update more tamper-proof (like only allow it in accesspoint mode, only at bootup is not helping, the module can easily be crashed by flooding http commands)  -> need to press button to start webserver
   -webpage: add button for firmware update, add button for spiffs update
*/


void setup() {
  delay(400);  // wait for power to stabilize
#ifdef SERIALDEBUG
  Serial.begin(115200); //comment the led init below if using serial
  Serial.println(F("\r\n\r\n*******************************"));  // todo: add actual build info here
  Serial.println(F("** Fablab Winti RFID CONTROL **"));  // todo: add actual build info here
  Serial.println(F("*******************************"));  // todo: add actual build info here
  Serial.println(F("\r\n\r\n"));  // todo: add actual build info here
#endif
  //**********************
  //FAILSAFE FACTORY RESET
  //**********************
  //press flash button immediateley after releasing the reset but not during reset (that will start the bootloader)
  forceFactoryReset(); //if button is pressed for 2 seconds, a factory reset is execuded


  //*****************
  //SOFTWARE INIT
  //*****************


  ESP.wdtDisable(); //disable the standard software watchdog (hardware watchdog still running)it did sometimes reset when disabling wifi due to long timeouts
  localTimeValid = false;  // set true once the time is set from NTP server
  ReadConfig();  // read configuration from eeprom, apply default config if invalid
#ifdef SERIALDEBUG
  printConfig(); //debug function
#endif
  SPIFFS.begin(); //init local file system
  //print SPIFFS content
#ifdef SERIALDEBUG
  String str = "";
  fs::Dir dir = SPIFFS.openDir("/");
  while (dir.next()) {
    str += dir.fileName();
    str += " / ";
    str += dir.fileSize();
    str += "\r\n";
  }
  Serial.print(str);
#endif

  userDBInit();

  //*****************
  //HARDWARE INIT
  //*****************
  Wire.begin(); //I2C, default pins: 4 & 5
  SPI.begin();
  displayinit(); //show bootup screen
  ConfigureWifi();  //connect to wifi
  RTCinit(); //init the local time from RTC
#ifndef SERIALDEBUG //cannot use LED when using serial out (hardware pin conflict)
  LEDinit(); //intialize WS2812 fastled library (comment this line if using Serial debugging output)
#endif
  delay(100);
  SDmanager();  // initialize SD card if present
  SDwriteLogfile("Boot");
  initRFID();
  playBeep(); //init the beeper by playing a short sound
  initOutput(); //initialize output pin

  display.print(F("Free heap:"));
  display.println(ESP.getFreeHeap(), DEC);
  display.display();
  display.print(F("EEPROM used:"));
  display.println(EE_END, DEC);
  display.display();
  delay(100);
  display.println(F("setup done"));
  display.display();

  delay(800);

  //test search speed:
#ifdef SERIALDEBUG
  Serial.println(F("full DB searchtest"));
  uint32_t starttime = millis();
  uint32_t uidtofind = 456;
  userDBfindentry(uidtofind);
  uint32_t endtime = millis();
  Serial.print(F("it took "));
  Serial.print(endtime - starttime);
  Serial.println(F("ms"));
#endif
  //print full user database:
#ifdef SERIALDEBUG
  userDBprintout();
#endif
  addEventToQueue(1, "" ); //send 'controller start' event
}
/*
  void sleepcallback()
  {
  Serial.println("I'm Back!");
  }
*/

long testtimestamp = 0;

void loop() {
  yield();
  ESP.wdtFeed(); //kick hardware watchdog (usually done in software watchdog interrupt which is disabled in setup)
  checkRFID();
  updateLED();  // update LED output
  
  if (webserver_active == false)
  {

    displayUpdate(); //when machine is in use, only update the display and monitor the RFID, WiFi is disabled when locked

    if (machineLocked) //only run wifi accessing stuff if user is NOT logged in (wifi is not 100% stable or has long timeouts)
    {
      wifiCheckConnection();

      checkButtonState();  // check GPIO0 button state
      checkPostLogoutDelay(); //switch machine off after some time after logout

      if (millis() > postlogoutmillis + 10000) //only check and send data after 10 seconds after logout, wifi is not yet connected before
      {
        UpdateDBfromServer(); //update the user database if necessary
        SDmanager();  // check SD card
        sendPendingEvents(false);  // send data out from events database and RAM queue
        timeManager(false); // check the local time
      }

    }
    else //machine is unlocked and in use
    {
      static uint16_t sendoutcounter;
      uint32_t minutestpassed = (getRtcTimestamp() - userStarttime) / 60;

      if (minutestpassed >= config.mPeriod)
      {
        uint16_t periodspassed = minutestpassed / config.mPeriod;
        if (periodspassed > sendoutcounter) //for each period, send one event
        {
          sendoutcounter++;
          //read currently logged in user from database (userentry contains last used card, not necessarily the current user)
          userdatabase.readRec(currentuser, EDB_REC userentry); //get the currently logged in user entry
          addEventToQueue(9, userentry.tagid , String(userentry.name) + " running" + String(sendoutcounter)); //event 9 = running (watchdog)
          sendPendingEvents(true);  //sends data to the event database since wifi is disconnected during machine use
        }
      }
      else
      {
        sendoutcounter = 0;
      }
    }

  }
  else //serve the config webpage (reboot to deactivate)
  {
    wifiCheckConnection();
    checkButtonState();  // check GPIO0 button state
    server.handleClient(); //handles http connections and webpage requests
    webSocket.loop();   // handles websocket requests
  }

  delay(180); //automatically adds some sleep mode, saving power, not necessary to manually put it to sleep (only works if connected to network)

}

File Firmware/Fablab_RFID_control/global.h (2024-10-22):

//#include <WiFiClientSecure.h>
#include "Fonts/g9regular.h"


#define SD_CSN_PIN 0
#define SERVERPACKETS 8   // number of server sendout packets (=event packet buffer in ram)
#define MAXKEYSIZE 512 //maximum allowed size of public key (cert.pem) in bytes (should be smaller than 500 bytes, not tested for larger keys)
#define KEYFILE "/key.pem" //name of the key file

#define DEFAULTSTRINGLENGTH 32 //strings stored in eeprom have this length by default (31 chars + termination)
#define SERVERCREDENTIALSTRINGLENGTH 55 //string length for server credentials (Cayenne credentials are up to 50 chars long)


//EEPROM definitions
#define EEPROMSIZE 1024
#define EE_START 8  //staring address of data (first 8 bytes can be used as identifiers and versioning)
#define EE_SSID_ADDR  EE_START                                      //base address for wifi passwords
#define EE_WIFIPASS_ADDR EE_SSID_ADDR+(MULTIWIFIS*DEFAULTSTRINGLENGTH)     //base address for wifi passwords
#define EE_NEXTWIFI_ADDR EE_WIFIPASS_ADDR+(MULTIWIFIS*DEFAULTSTRINGLENGTH)    //address for next wifi credentials to (over)write (wifi multi)
#define EE_DEVICENAME_ADDR EE_NEXTWIFI_ADDR+SERVERCREDENTIALSTRINGLENGTH //address for device name (accesspoint name, default: RFIDnode-xx)
#define EE_DEVICEPASS_ADDR EE_DEVICENAME_ADDR+DEFAULTSTRINGLENGTH   //address for device passworkd (accesspoint passworkd, default: 12345678)
#define EE_NTP_ADDR EE_DEVICEPASS_ADDR+DEFAULTSTRINGLENGTH          //address for NTP server name string
#define EE_IP_ADDR EE_NTP_ADDR+DEFAULTSTRINGLENGTH                  //address for static IP
#define EE_NETMASK_ADDR EE_IP_ADDR+4                                //address for static Netmask IP
#define EE_GATEWAY_ADDR EE_NETMASK_ADDR+4                           //address for static Gateway IP
#define EE_DHCP_ADDR EE_GATEWAY_ADDR+4                              //address for 'use DHCP' boolean
#define EE_TIMEZONE_ADDR EE_DHCP_ADDR+4                             //address for timezone, signed uint8_t (currently not used)
//machine settings
#define EE_MID_ADDR EE_TIMEZONE_ADDR+1                              //address for machine ID, uint8_t
#define EE_MPRICE_ADDR EE_MID_ADDR+1                                //address for machine price, uint16_t
#define EE_MPERIOD_ADDR EE_MPRICE_ADDR+2                            //address for machine pricing period, uint8_t
#define EE_MMINPERIODS_ADDR EE_MPERIOD_ADDR+1                       //address for machine min. pricing periods billed, uint8_t
#define EE_MSWITCHOFFDELAY_ADDR EE_MMINPERIODS_ADDR+1               //address for machine switch-off delay, uint16_t
#define EE_MACHINENAME_ADDR EE_MSWITCHOFFDELAY_ADDR+2               //address for machine name, string
//database server settings
#define EE_SERVERIP_ADDR EE_MACHINENAME_ADDR+DEFAULTSTRINGLENGTH    //address for server IP address, 32byte string (string can be an ip like "192.168.1.1")
#define EE_SERVERPORT_ADDR EE_SERVERIP_ADDR+DEFAULTSTRINGLENGTH     //address for server port, uint16_t
//RFID settings
#define EE_RFIDKEY_ADDR EE_SERVERPORT_ADDR+2                        //address for access key for RFID data
#define EE_RFIDCODE_ADDR EE_RFIDKEY_ADDR+6     //address for access code that needs to match on RFID card
#define EE_ADMINUID_ADDR EE_RFIDCODE_ADDR+16     //address for one admin UID which always has access, once set, even a complete reset will not delete this
#define EE_WEBPASS_ADDR EE_ADMINUID_ADDR+4     //address for password for config webpage access
#define EE_WEBUSER_ADDR EE_WEBPASS_ADDR+DEFAULTSTRINGLENGTH     //address for username for config webpage access
#define EE_SERVERAPIKEY_ADDR EE_WEBUSER_ADDR+DEFAULTSTRINGLENGTH     //address for key for server API access
#define EE_SERVERAPIUSER_ADDR EE_SERVERAPIKEY_ADDR+DEFAULTSTRINGLENGTH     //address for username for server API access
//additional settings for version 1
#define EE_MMINPPRICE_ADDR EE_SERVERAPIUSER_ADDR+DEFAULTSTRINGLENGTH //address for machine min. periods price, uint16_t

#define EE_END EE_MMINPPRICE_ADDR+2                                  //address reserved

//additional config stuff needed:
/*
  -webpage login credentials
  -RFID card sector access codes
  -RFID card secret confirmation key
  -three admin UIDs (admins always have access, even after factory reset)
  -Server API user and key (two strings)
  todo: make the config use fixed string lengths as char arrays, read and write the full struct in one go making it a lot more flexible!
  can use mystring.toCharArray(config.thisstring, mytring.length()+1); to copy a string to char array and String mystring = String(config.thisstring) to convert it back
*/


//function prototypes (todo: need to clean up the header file depedency mess!)
void wifiAddAP(String name, String password);
time_t getRtcTimestamp(void);
void userDBpurge(void);
bool handleHTTPRequest(String path);
void handleFileUpload();
void webSocketEvent(uint8_t num, WStype_t type, uint8_t * payload, size_t lenght);


// global variables
Adafruit_SSD1306 display(0); //do not use reset pin
ESP8266WebServer server(80);  // The Webserver
//AsyncWebServer server(80);  // The Webserver
//AsyncWebSocket ws("/ws");

WebSocketsServer webSocket = WebSocketsServer(81);
WiFiClient espClient;
RtcDS3231<TwoWire> RTC(Wire); //DS3231 RTC clock on I2C


// WiFiClientSecure SSLclient; //secure connections
// uint8_t* SSLspacebloackreservation;

uint8_t APactive = 0;  // is zero if AP is deactivated, 1 if active (set to 1 to launch accesspoint mode)
bool refreshUserDB = true; //update the user database immediately if set to true (do so on bootup)
bool userDBupdated = false;
bool machineInfoUpdated = false; //set to true once the local machine info is updated from server(happens after bootup just before userDB is updated)
bool SDcardOK = false;
bool serverhealthy = false; //set to false if server connection fails multiple times, request time is then decreased to not hinder the usage of the controller by blocking login/logout events, set to true if server connection successful
bool localTimeValid;
bool RTCTimeValid = false; //is set true after setting the RTC successfully
bool machineLocked = true;
uint32_t userStarttime; //UNIX timestamp at start of machine use
uint32_t userStoptime; //UNIX timestamp at logout
uint32_t postlogoutmillis; //time after logout (used to not permanently having to check the RTC)

uint8_t RFIDtagprogrogramming = 0; //flag used to program blank rfid cards (flag = 1) or to blank already programmed cards (flag = 2)
uint8_t websocket_connected = 0;
bool webserver_active = false; //set true if webserver is started
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

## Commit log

2017-06-03 Initial project commit
    PCB rev. 1 is done but not veryfied, license for hardware added
    [Fablab_RFID_conroller_V0.1.brd, Fablab_RFID_conroller_V0.1.sch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]
2017-06-04 add SD card to BOM
    [Fablab_RFID_controller_BOM.ods]
2017-06-11 removed OTA support, changed LED behaviour
    OTA was replaced by secure web update
    [WiFi.h]
2017-06-11 removed watchdog timer
    it conflicts somehow with the fastled library. also the controller
    should never atuomatically reboot
2017-06-11 sound support for final version
    changed pin from debug to final, added login and logout sound, changed
    function names
2017-06-11 reorganized timer management
    RTC runs on epoch (UNIX) time, local clock runs on local time, including
    timezone and automatic DST (europe)
2017-06-11 led support and global variable added
2017-08-17 added event generation functions
    and debugged SD card database saving, now fully working
    also added proper timestamp string generation
    plus some small bugfixes
    [Fablab_RFID_control.ino, RFID.h, SDcard.h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]
2017-08-20 started updating config stuff, started on RFID advanced auth
    -added handling of more eeprom config variables
    -added support to make all config page traffic websocket based (webpage
    still needs updating)
    -changed server sendouts to use data from config (no more fixed strings)
    -added password support for config page access
    -cleaned up the todo list
    [Fablab_RFID_control.ino, RFID.h, ServerRequests.h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]
2017-08-22 Bugfixes & Working on Config Webpage
    trying to get the config page up to speed, partially working but still
    work in progress
    [Fablab_RFID_control.ino, ServerRequests.h, WiFi.h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]
2017-08-26 big config page update
    -fixed some bugs on webpage and in firmware
    -added config support
    -website now downloads machine list from server automatically
    -changed ajax loader.gif
    -added firmware and spiffs image file update directly from the server
    (triggered on config page)
    -changed behaviour of user button: config page now only accessible if
    button is pressed (for security reasons)
    -added display messages in server mode
    [Fablab_RFID_control.ino, SDcard.h, ServerRequests.h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]
2017-08-26 updated schematic with errata
    [Fablab_RFID_conroller_V1.dxf, Fablab_RFID_conroller_V1.sch]
2017-08-26 removed update server
    it is no longer needed thanks to http update
    [Fablab_RFID_control.ino, global.h]
2017-09-08 bugfixes & cosmetics
    [Fablab_RFID_conroller_V1.brd, Fablab_RFID_conroller_V1.sch]
2017-12-30 RFID and config Update
    - added framework for RFID authentication using the access key and a
    passphrase saved on the card, configurable on the webpage
    -Added a few variables to the config
    -Made web page credentials configurable
    -Prepared for the use of an API key, it can be entered on the webpage
    -changed factory reset: can now be done before any code runs, as a
    safety measure
    -prepared webpage and config for the use of a admin UID which will be
    granted access always, even if no database is available
    [Fablab_RFID_controller_BOM.ods]
2018-01-21 updated for new server version
    -changed api URI to /api/...
    -changed event number definitions
    -added error logs
    -added logs for unsuccessful tag access
    -updated BOM
    -added tag time verification
    -changed time string output format
    [Fablab_RFID_controller_BOM.ods]
2018-01-23 bugfix: writing to nonexisting SD card no more
    [RFID.h, SDcard.h, ServerRequests.h]
2018-01-25 added status icons
    also added som additional compiling info, it now works on arduino 1.8.5
    with ESP version 2.4.0 (which it did not before, not sure what change
    made that possible)
    Status icons is work in progress.
2018-07-16 Add missing global variable.
    [global.h]
2018-07-16 Add hand-drawn fonts and replace all use of other small fonts by them.
    [Fablab_RFID_control.ino, display.h, global.h]
2018-07-16 Fix status icons.
    The previous ones only displayed pixel garbage for me.
    [display.h]
2018-08-12 refactoring & minor fixes
    forgot to commit for a long time... only minor code changes
    [Fablab_RFID_control.ino, LED.h, RFID.h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]
2018-08-12 fixed errors after merging pull request
    also made server connection timeout shorter to avoid long delays in
    login if server is not available
    [SDcard.h, ServerRequests.h, display.h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]
2018-11-25 minor bugfixes
    -added login/logout function of admin tag also during a websocket
    session
    [Fablab_RFID_control.ino, RFID.h, SDcard.h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]
2019-04-29 stability update and added post logout switch delay
    disabling wifi during login times to increase stability (hopefully). had
    to add a delay before disabling wifi or it would crash very often...
    also some minor bugfixes here and there.
    [Fablab_RFID_control.ino, RFID.h, SDcard.h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]
2019-05-01 stability improvement added post logout user data display
    disabled software watchdog,
    improved sendout/sd saving handling
    after logout, time is still displayed for 10 sec
    no more crashes (so far) when disabling wifi
    [Fablab_RFID_control.ino, RFID.h, SDcard.h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]
2019-05-12 major update, added fatfs, added new way of secure connection, added more machine options
    plus some code cleanup, stability improvement yet again, added log to SD
    card every time interval. still need to do price calculation but
    everything is prepared for that.
    [RFID.h, ServerRequests.h, WiFi.h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]
2020-02-23 update for arduinojson v 6.x
    updated to use new version of arduinojson
2020-02-28 bugfix in json parsing
    [Fablab_RFID_control.ino, ServerRequests.h]
2020-03-07 LED update bugfix, Serial debug output refactor
    [Fablab_RFID_control.ino, WiFi.h, global.h]
2023-12-26 Fix use of uninitialized variable.
    It could randomly cause logs to be sent to the server without a tid.
    [ServerRequests.h]
2023-12-26 Send log events to the server in the order they were created.
    The previous partly-reversed order made it hard to interpret them on the server when timestamps were not chronological due to network time updates or RTC failure.
    The database in SPIFFS and the queue in RAM, in that order, now form a combined FIFO queue. Entries are sent to the server directly from the RAM queue if possible, but if not, moved to the flash database after a while to preserve them in case of power loss.
    [Fablab_RFID_control.ino, SDcard.h, ServerRequests.h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]
2023-12-28 Fix failing database update with 4 or more user entries.
    Trying to parse up to 5 entries at once did not work, it already ran into a NoMemory error at 4 fully specified entries with the 512 byte document buffer. Parse them one by one instead, following https://arduinojson.org/v6/how-to/deserialize-a-very-large-document/ . This also gets rid of the buggy splitting logic that would be confused by '}' appearing in string literals or subobjects.
    [ServerRequests.h]
2024-05-09 Address erratum: Fix +5V connection of relay coil.
    [Fablab_RFID_conroller_V1.brd, Fablab_RFID_conroller_V1.sch]
2024-05-09 Address erratum: Replace diode D2 by 10k resistor R13.
    [Fablab_RFID_conroller_V1.brd, Fablab_RFID_conroller_V1.sch, Fablab_RFID_controller_BOM.ods]
2024-05-09 Regenerate PDF and Gerber files for version 1.1.
    [Fablab_RFID_conroller_V1.GBP, Fablab_RFID_conroller_V1.GTL, Fablab_RFID_conroller_V1.GTO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]
2024-10-22 Observe the minimum periods price for the cost display.
    Adjust to the current server that provides this field in the machine database.
    The additional configuration field requires introducing versioning in the EEPROM data structure.

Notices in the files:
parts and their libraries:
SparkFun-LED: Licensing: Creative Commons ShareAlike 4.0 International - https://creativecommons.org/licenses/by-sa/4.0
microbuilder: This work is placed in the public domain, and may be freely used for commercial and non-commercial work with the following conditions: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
